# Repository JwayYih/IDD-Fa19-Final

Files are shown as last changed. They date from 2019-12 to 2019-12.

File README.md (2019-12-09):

# IDD Final - Interactive Nightstand

## The Project
We are creating an interactive LED nightstand. The goal is to have 4 distinct LED strips inlayed in the surface of the table top which can be operated by a capactive touch sensing interaction.

## Step 1: The Woodworking
Designing the table in SolidWorks

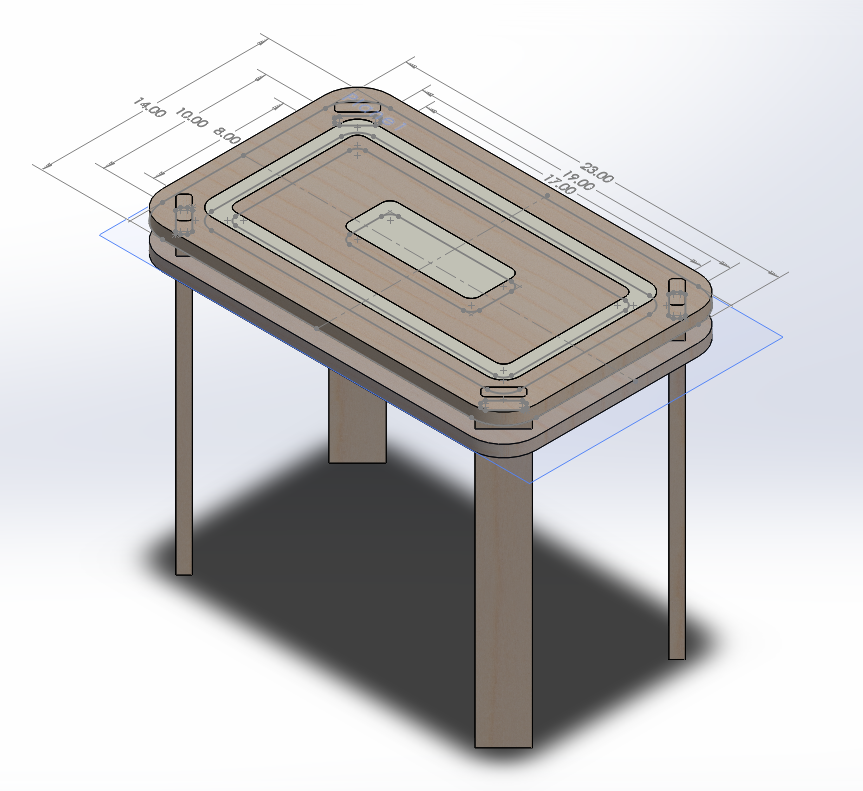
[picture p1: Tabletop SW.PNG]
Tabletop SW


SolidWorks part was converted to an SVG file for Shaper Origin to recognize

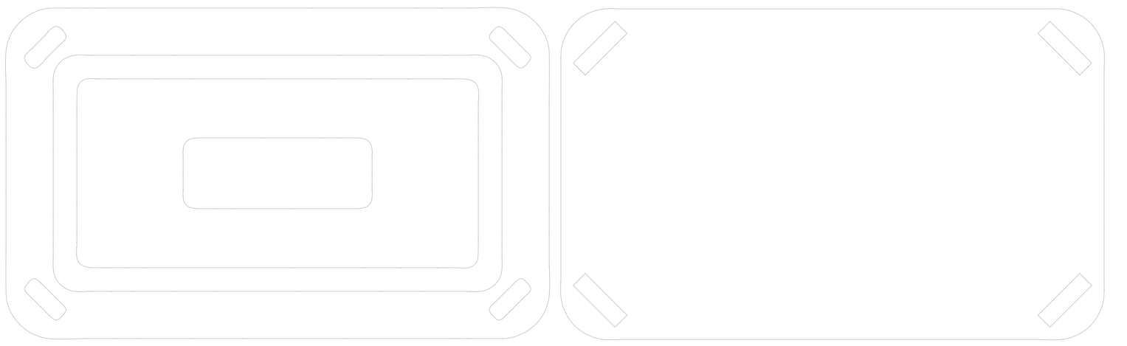
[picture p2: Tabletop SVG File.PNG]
Tabletop SVG File


Origin uses computer vision to create and augmented reality workspace. It uses a patterned tape which is placed on the work surface to register its location. Then with its precision motors it precisely cuts along the uploaded image.

Used the Shaper Origin handheld CNC to cut out the table top

[Cuttting Out Tabletop Video](https://photos.app.goo.gl/qifHks3SJ6dKoCYE8)

Here is the setup with the Shaper Tape

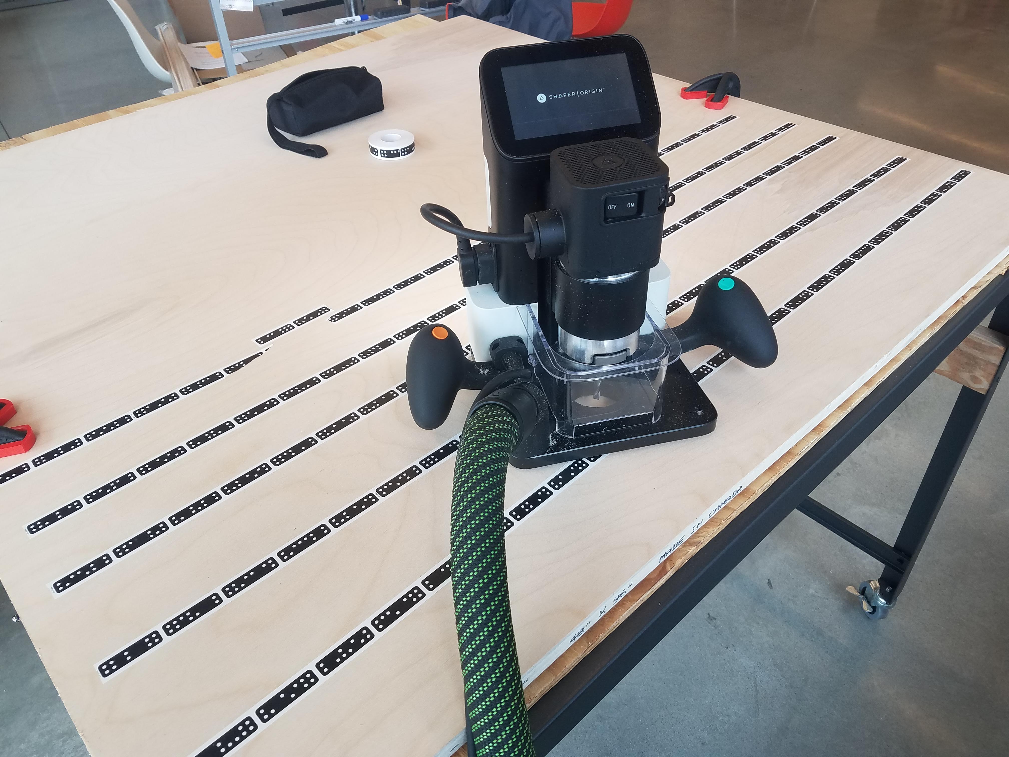
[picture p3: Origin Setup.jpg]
Origin Setup


This is the touch interface used to load and place designs as well as adjust all cut parameters (depth, inside/outside/pocket cut, offsets, etc.)

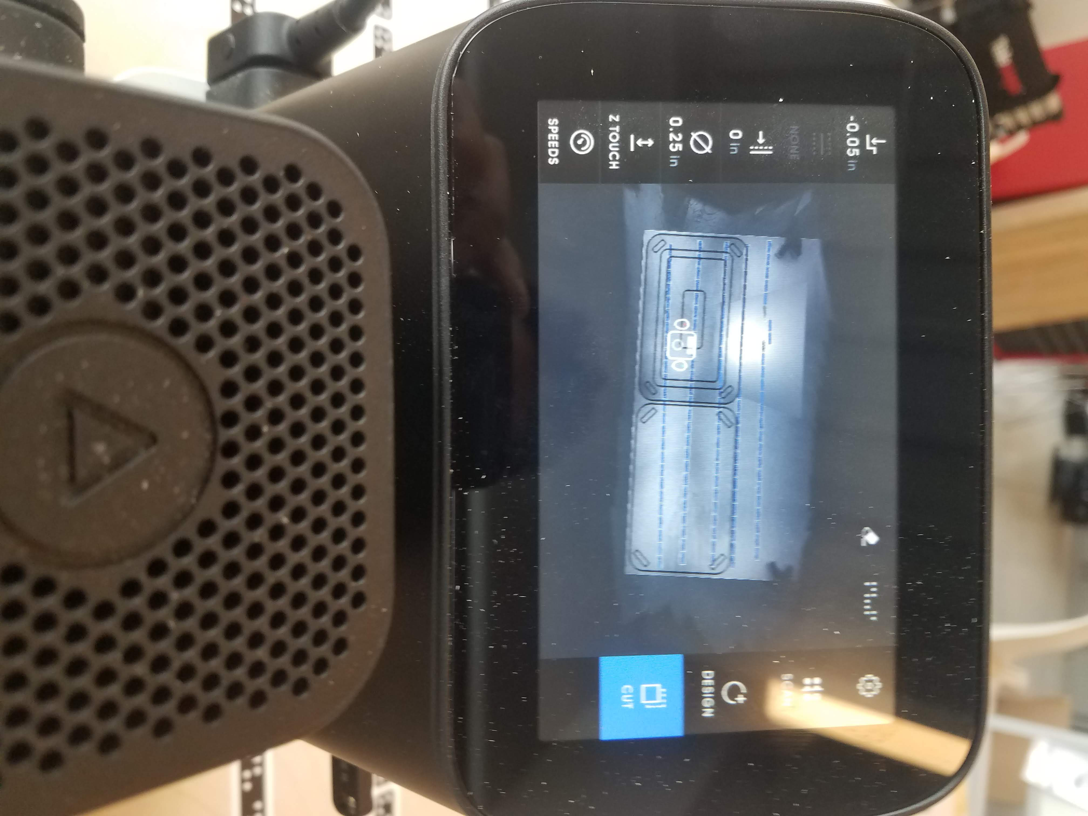
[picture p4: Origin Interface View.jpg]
Origin Interface View


Here are the cut outs of the top two surfaces

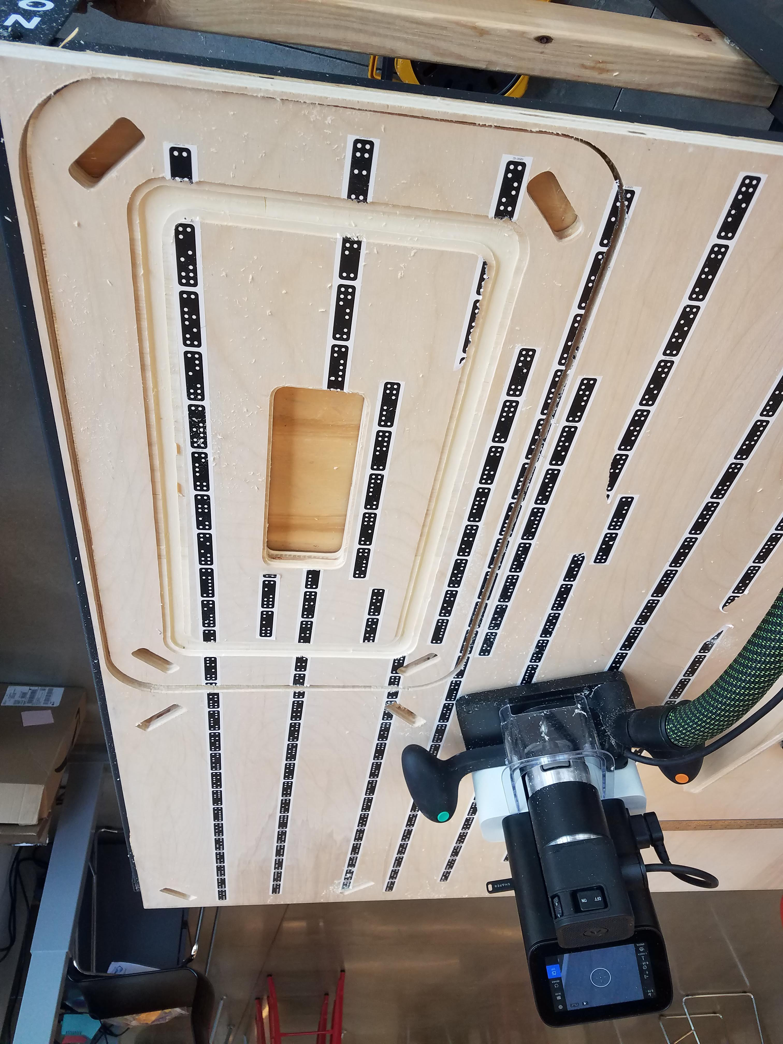
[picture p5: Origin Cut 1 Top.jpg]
Origin Cut 1 Top

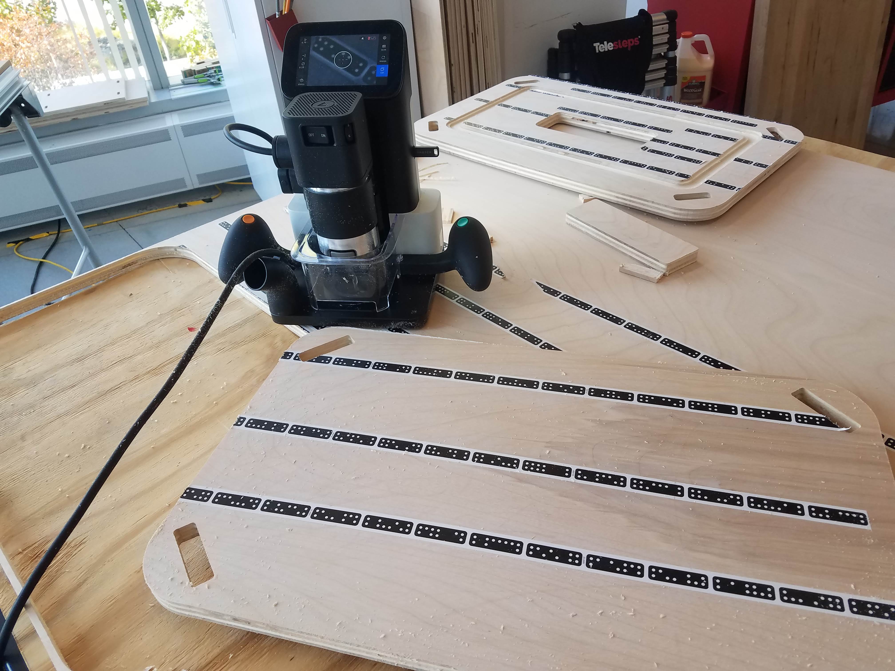
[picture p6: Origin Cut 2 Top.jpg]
Origin Cut 2 Top


Used the Festool track saw to cut out the legs

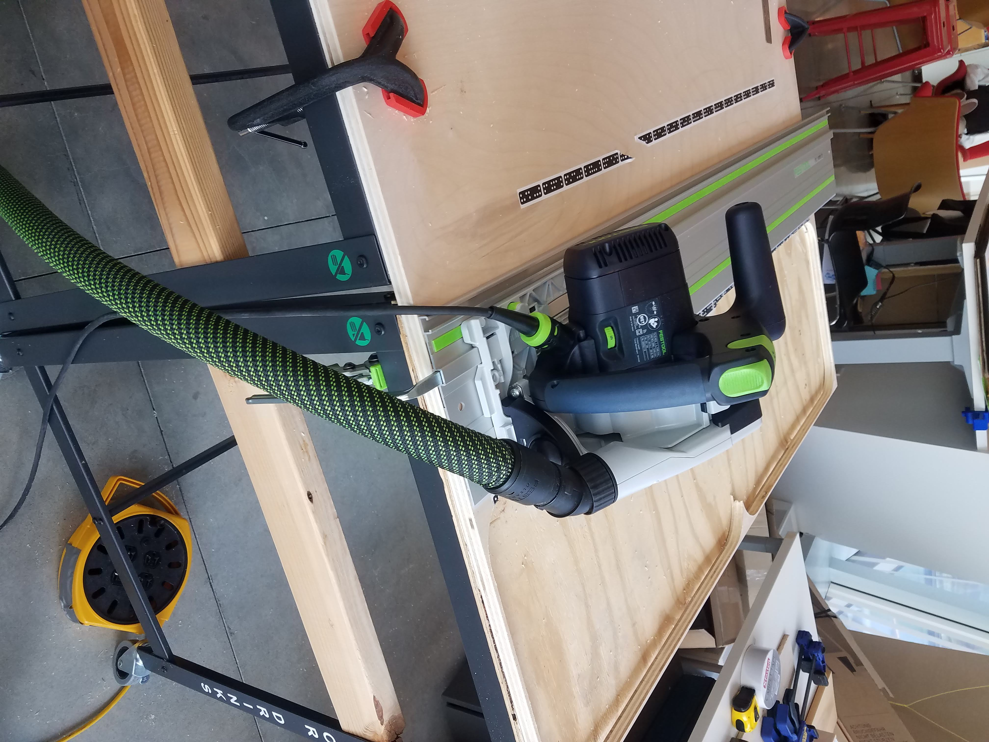
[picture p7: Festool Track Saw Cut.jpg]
Festool Track Saw Cut


All components cut out
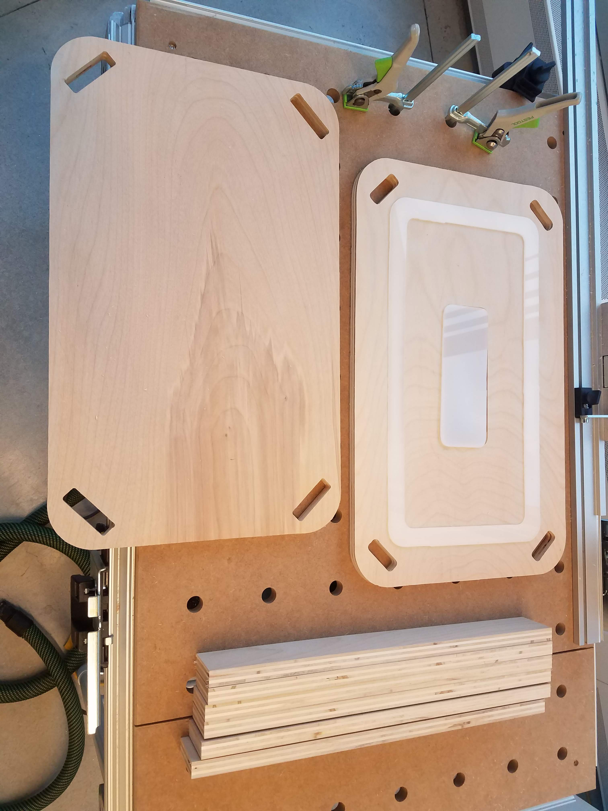
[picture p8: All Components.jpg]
All Components


Used the Shaper Origin and a tenon jig to create the mating tenons on the legs

All the completed components in an exploded view

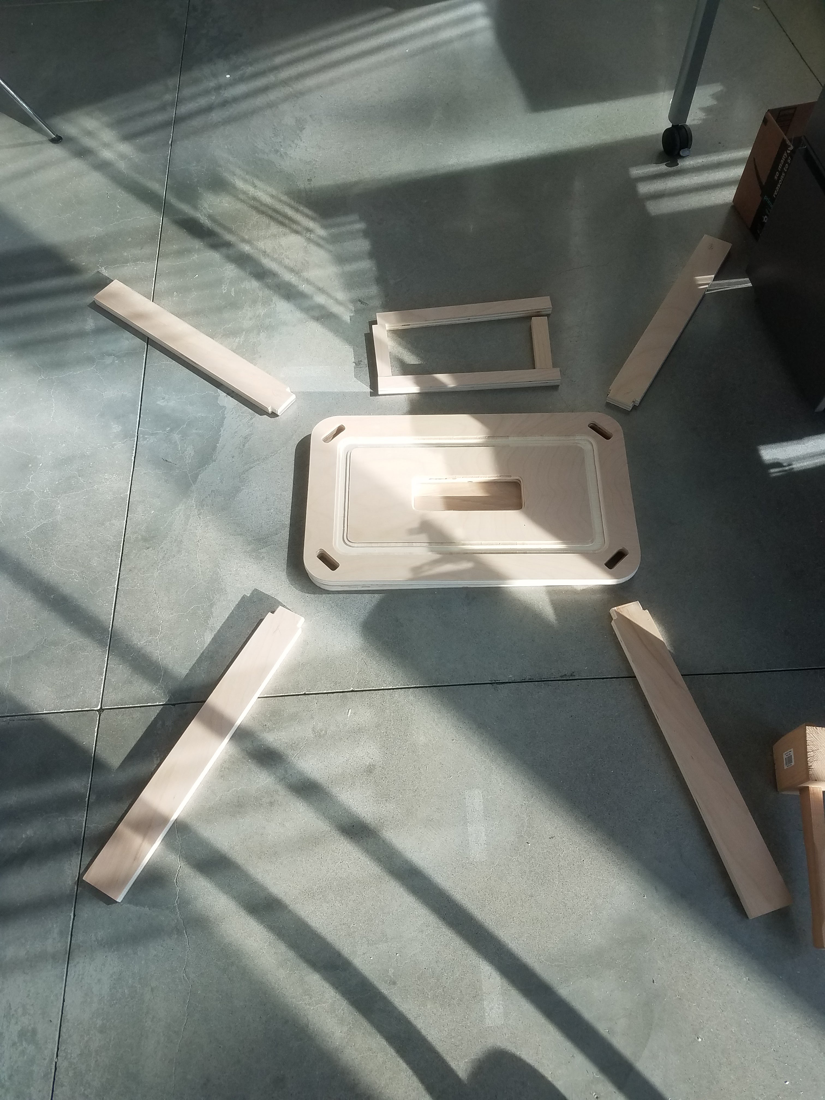
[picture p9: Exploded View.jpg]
Exploded View


## Step 2: The Circuit

Utilized the Capacitive Sensing Library created by Paul Badger
https://playground.arduino.cc/Main/CapacitiveSensor/

Created a single cap sense sensor to turn on and off an onboard LED. Circuit built from a combination of [cap sensing](https://www.youtube.com/watch?v=lqg_Ze_OiiY) and [LED control] (https://www.youtube.com/watch?time_continue=152&v=5M24QUVE0iU&feature=emb_title)

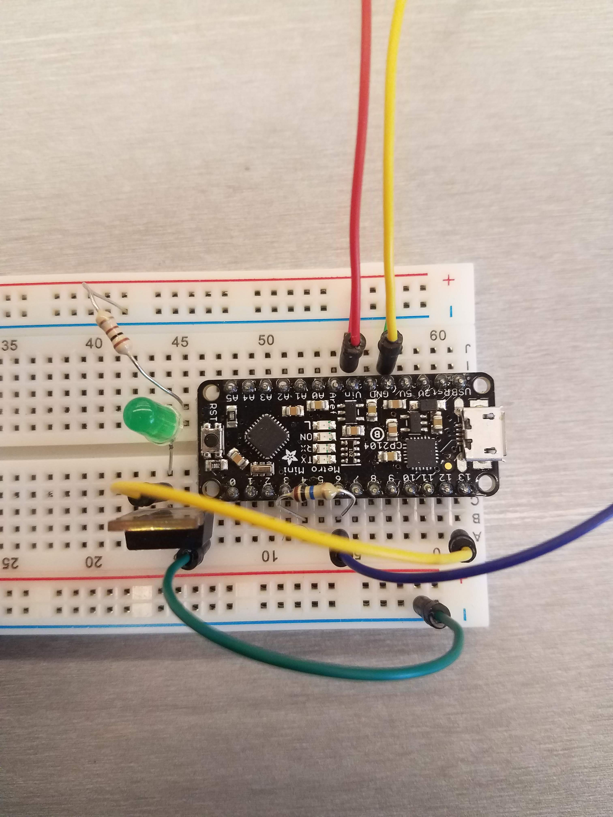
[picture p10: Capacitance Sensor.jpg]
Cap Sensor


The [LED strips](https://www.amazon.com/gp/product/B074N1FC56/ref=ppx_yo_dt_b_search_asin_title?ie=UTF8&psc=1) we used required a 12V external power source, but the Arduino only outputs 5V. So we used the 5V output as a switch for an NPN transistor that would switch on and off the external 12V source to the LED.

Originially, we tried to power the Arduino with a laptop and the LED separately with a 12V source, but this caused some issues (lights could be turned on, but not turned off with cap sensing). We believe there may have been some inconsistencies with the ground reference. To address this we decided to run both the LED and the Arduino off the 12V source. This resolved the issue. The circuit was then repeated 4x, one for each LED strip. This [code](https://github.com/JwayYih/IDD-Fa19-Final/blob/master/CapacitiveSensorTest.ino) was used to run the circuit.

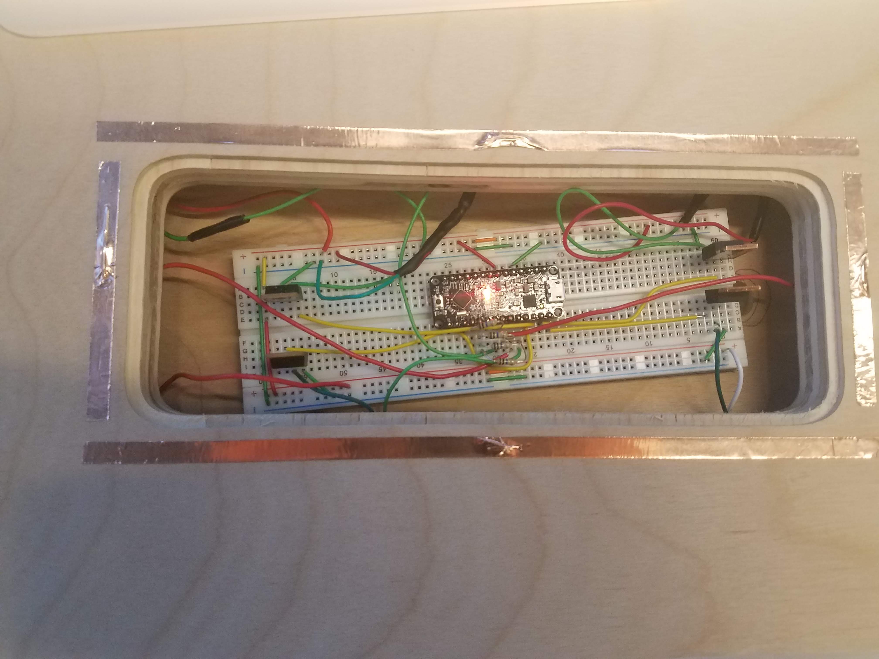
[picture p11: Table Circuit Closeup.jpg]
Final Circuit 1

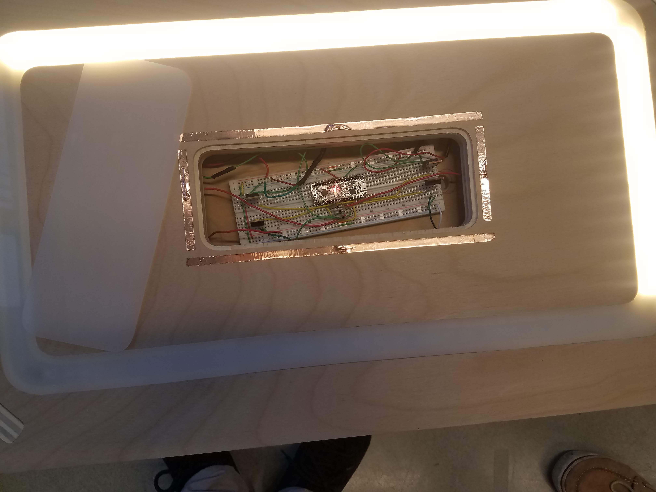
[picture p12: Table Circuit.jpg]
Final Circuit 2

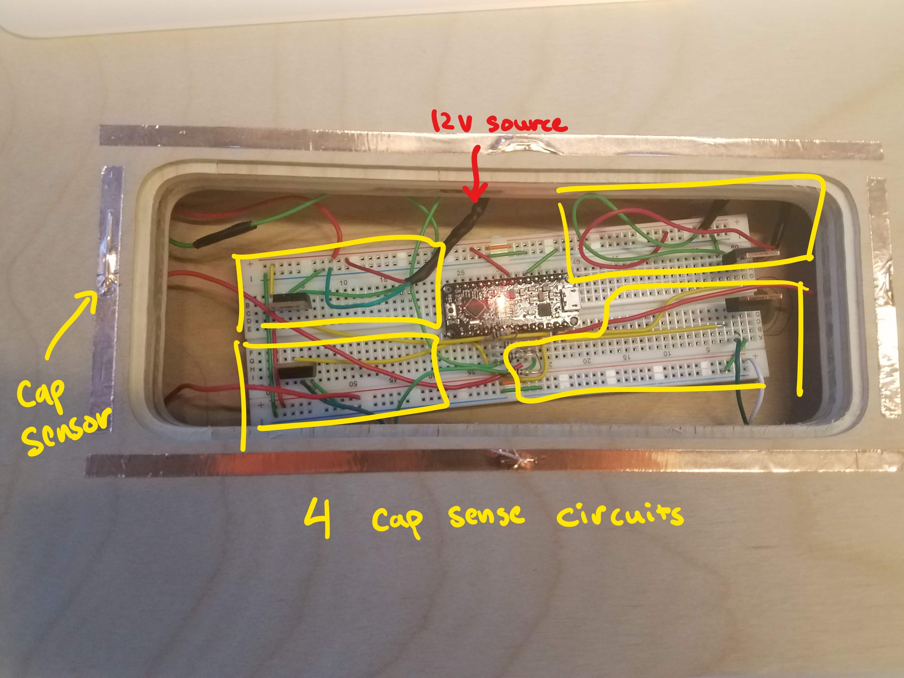
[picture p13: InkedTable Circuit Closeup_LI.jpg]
Final Circuit 3


## Step 3: The Assembly

The table was ultimately designed to be press fit together. There is no glue holding it together.

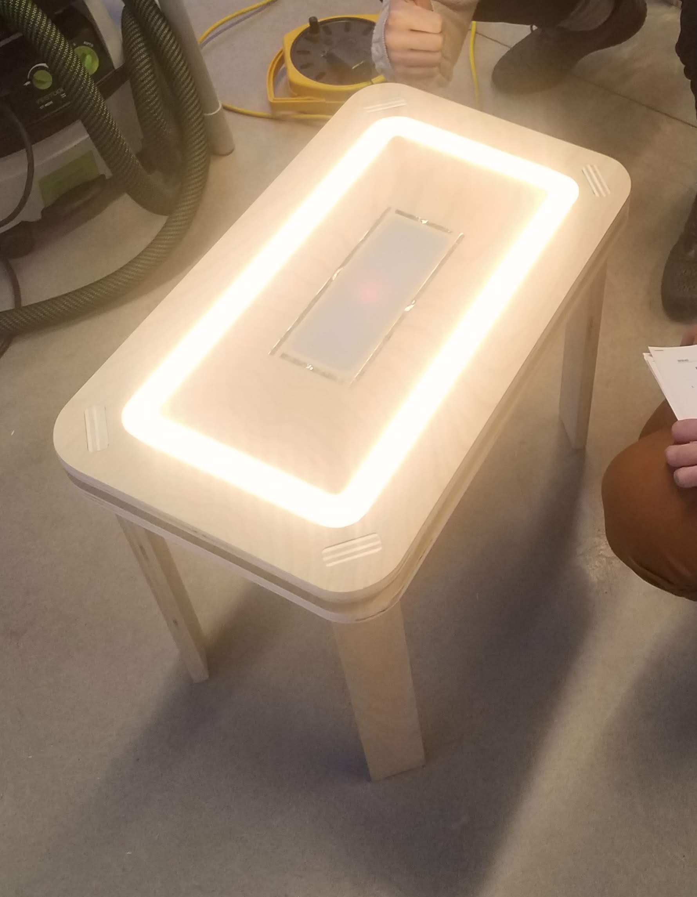
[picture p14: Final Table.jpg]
Final Table


[Demo Video](https://github.com/JwayYih/IDD-Fa19-Final/blob/master/Demo%20Video.mp4)

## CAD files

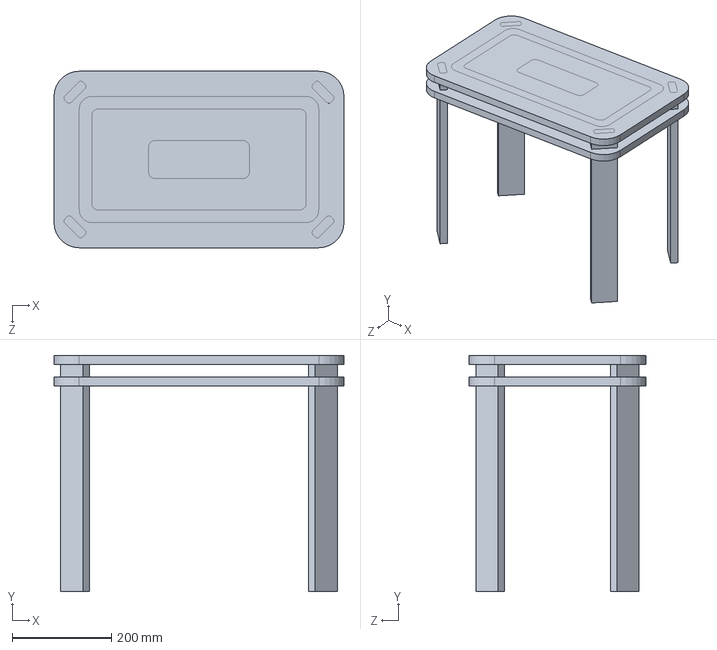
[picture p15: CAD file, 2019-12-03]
IDD Table.SLDPRT
584.2 x 475.5 x 355.6 mm

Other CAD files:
IDD Table.DXF

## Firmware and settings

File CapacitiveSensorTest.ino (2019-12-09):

#include <CapacitiveSensor.h>
CapacitiveSensor Sensor1 = CapacitiveSensor(4, 6);
CapacitiveSensor Sensor2 = CapacitiveSensor(4, 7);
CapacitiveSensor Sensor3 = CapacitiveSensor(4, 8);
CapacitiveSensor Sensor4 = CapacitiveSensor(4, 9);

long val1;
long val2;
long val3;
long val4;
int pos1;
int pos2;
int pos3;
int pos4;
#define led1 13
#define led2 12
#define led3 11
#define led4 10


void setup()
{
Serial.begin(9600);
pinMode(led1, OUTPUT);
pinMode(led2, OUTPUT);
pinMode(led3, OUTPUT);
pinMode(led4, OUTPUT);
}



void loop()
{
val1 = Sensor1.capacitiveSensor(30);
val2 = Sensor2.capacitiveSensor(30);
val3 = Sensor3.capacitiveSensor(30);
val4 = Sensor4.capacitiveSensor(30);
//Serial.println(val);
//LED 1
  if (val1 >= 1000 && pos1 == 0)
  {
    digitalWrite(led1, HIGH);
    pos1 = 1;
    delay(300);
  }

  else if (val1 >= 1000 && pos1 == 1)
  {
    digitalWrite(led1, LOW);
    pos1 = 0;
    delay(300);
  }
  
//LED 2
  else if (val2 >= 1000 && pos2 == 0)
  {
    digitalWrite(led2, HIGH);
    pos2 = 1;
    delay(300);
  }
    else if (val2 >= 1000 && pos2 == 1)
  {
    digitalWrite(led2, LOW);
    pos2 = 0;
    delay(300);
  }
  
//LED 3
  else if (val3 >= 1000 && pos3 == 0)
  {
    digitalWrite(led3, HIGH);
    pos3 = 1;
    delay(300);
  }
    else if (val3 >= 1000 && pos3 == 1)
  {
    digitalWrite(led3, LOW);
    pos3 = 0;
    delay(300);
  }

//LED 4
  else if (val4 >= 1000 && pos4 == 0)
  {
    digitalWrite(led4, HIGH);
    pos4 = 1;
    delay(300);
  }
    else if (val4 >= 1000 && pos4 == 1)
  {
    digitalWrite(led4, LOW);
    pos4 = 0;
    delay(300);
  }
delay(10);
}
